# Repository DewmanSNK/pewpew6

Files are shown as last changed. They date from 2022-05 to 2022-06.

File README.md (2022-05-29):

# pewpew6
## Re-map and Rapid Fire
### Introduction

Based on buffi's original openpewpew, pewpew6 is an Arduino Nano based device for rapid fire and button remap in a JAMMA arcade cabinet. Pewpew6 supports up to 6 input buttons and can map those to any of 6 outputs. It simply connects in-line between the control panel buttons and the existing wiring harness. In an unconfigured state pewpew6 will provide simple passthrough, making it as though pewpew6 was not even installed. To load custom rapid fire and button remapping, pewpew6 leverages NFC cards. An NFC card card be configured with a desired auto fire and button remapping configuration. When the card is in proximity of the NFC reader, PewPew6 will change configuration on the fly and apply the rapid fire and remap settings stored on the card. This allows you to preconfigure you favorite buttons mappings and/or auto fire rates and store those on any number of NFC cards. 

### pewpew6 Features

- 6 button input and 6 outputs
- Button Remap
- Separate frames_on and frames_off rapid fire settings
- NFC card reader for loading settings
- 6 LED indicators show per button configuration

### NFC Card Format

Settings are stored in a 'Text Record' on the NFC card. 

Each line consists of the following comma separated values:  
(Button)(rapid enable)(frames_on)(frames_off)(Output)  

-Only one button definition per line  
-Last button definition ends with ';'  

Line Example
-------
A,0,1,1,1 = Button A, No auto fire enabled, 1 frame_on, 1 frame_off, Output 1  
**Note - When auto fire is disabled, the frame_on/frame_off vales are meaningless**  

Example Text Record 1:
--------------------
A,0,1,1,1  
B,0,1,1,2  
C,0,1,1,3  
D,0,1,1,4  
E,0,1,1,5  
F,0,1,1,6;  

The example text record 1 shown above displays the correct format. The settings in this example are the default settings stored in the Arduino.   
No rapid fire, no remapping - passthrough only.  

Example Text Record 2:
--------------------
A,0,1,1,1  
B,1,2,2,1  
C,1,1,4,1  
D,1,4,4,1  
E,1,10,1,1  
F,1,5,5,1;  

The example text record 2 shown above maps all 6 buttons to JAMMA-1  
Button A has no rapid fire, 1 frame_on, 1 frame_off, JAMMA-1  
Button B has rapid fire enabled, 1 frame_on, 1 frame_off, JAMMA-1  
Button C has rapid fire enabled, 1 frame_on, 4 frame_off, JAMMA-1  
Button D has rapid fire enabled, 4 frame_on, 4 frame_off, JAMMA-1  
Button E has rapid fire enabled, 10 frame_on, 1 frame_off, JAMMA-1  
Button F has rapid fire enabled, 5 frame_on, 5 frame_off, JAMMA-1  

Example Text Record 3:
--------------------
A,0,1,1,1  
B,0,2,2,2  
D,0,4,4,3  
E,0,10,10,4;  

The example text record 3 shown above is a fighting game example.  
Only 4 buttons are mapped, all buttons have rapid fire disabled - this is used only for button remapping and no rapid fire.

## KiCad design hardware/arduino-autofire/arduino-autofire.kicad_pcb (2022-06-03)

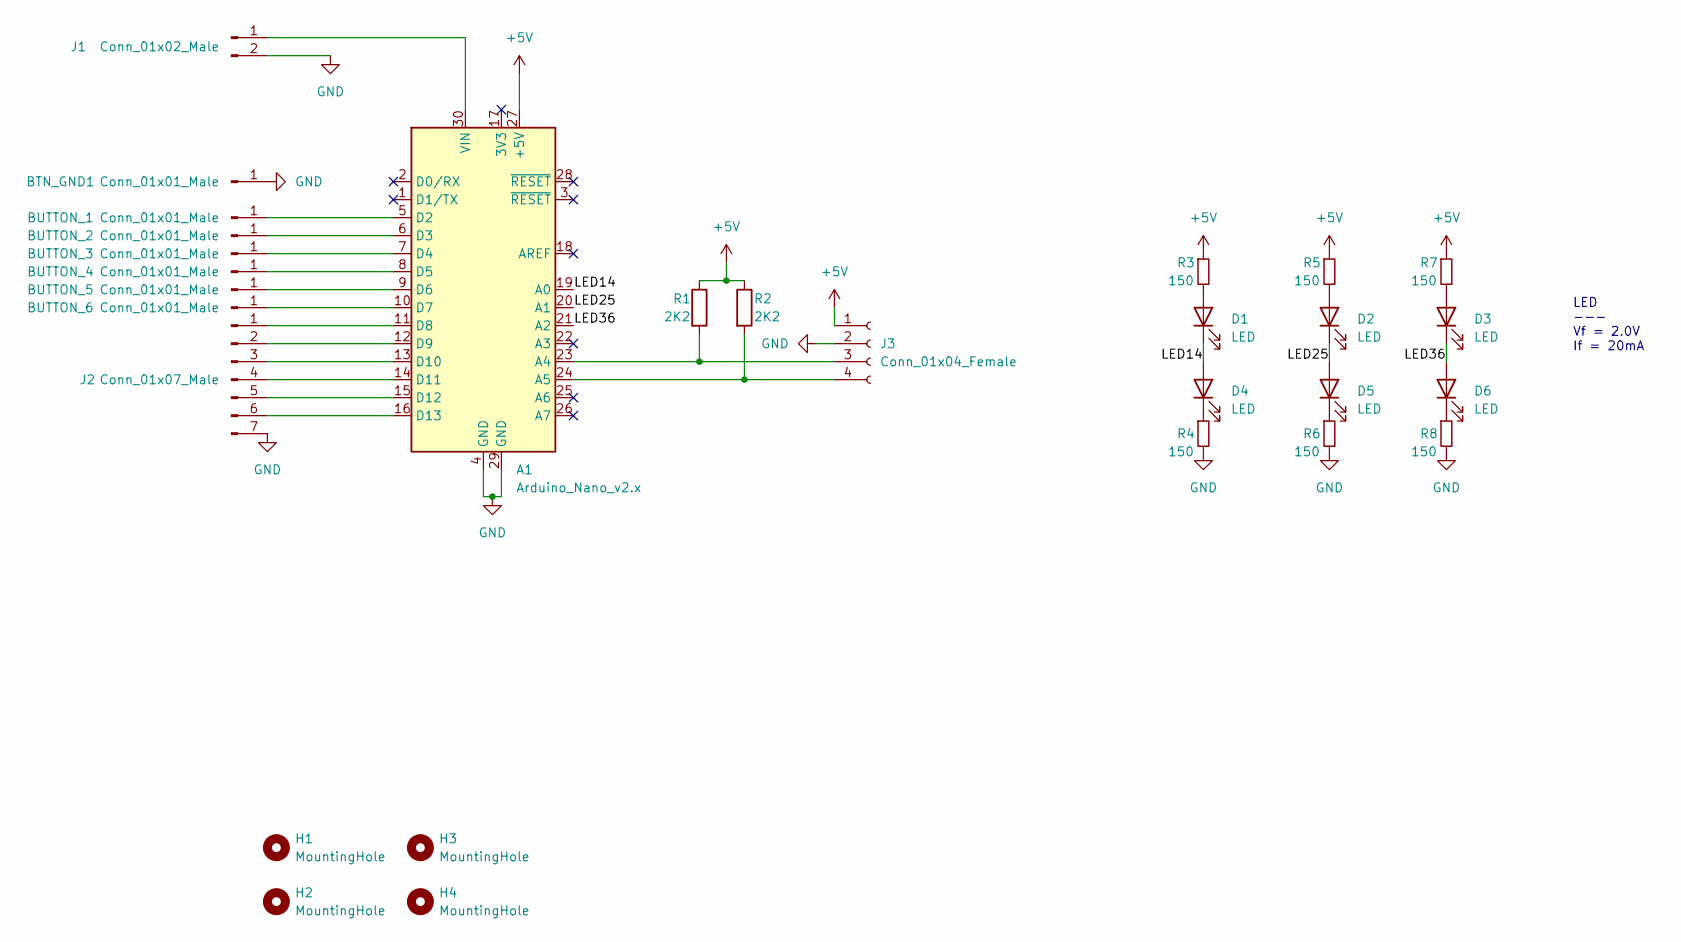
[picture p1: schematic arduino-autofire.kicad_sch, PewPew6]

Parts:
A1: Arduino_Nano_v2.x; Arduino_Nano_3D
BTN_GND1: Conn_01x01_Male; RA_Pin_D1.3mm_5.0mm
BUTTON_1, BUTTON_2, BUTTON_3, BUTTON_4, BUTTON_5, BUTTON_6: Conn_01x01_Male; RA_Pin_D1.3mm_5.0mm
D1, D2, D3, D4, D5, D6: LED; LED_0805_2012Metric_Pad1.15x1.40mm_HandSolder
H1, H2, H3, H4: MountingHole; MountingHole_3.2mm_M3
J1: Conn_01x02_Male; JST_EH_S2B-EH_1x02_P2.50mm_Horizontal
J2: Conn_01x07_Male; JST_EH_S7B-EH_1x07_P2.50mm_Horizontal
J3: Conn_01x04_Female; JST_EH_S4B-EH_1x04_P2.50mm_Horizontal
R1, R2: 2K2; R_0805_2012Metric_Pad1.20x1.40mm_HandSolder
R3, R4, R5, R6, R7, R8: 150; R_0805_2012Metric_Pad1.20x1.40mm_HandSolder

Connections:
+5V: A1.27 (+5V), J3.1, R1.1, R2.1, R3.1, R5.1, R7.1
/LED14: A1.19 (A0), D1.1 (K), D4.2 (A)
/LED25: A1.20 (A1), D2.1 (K), D5.2 (A)
/LED36: A1.21 (A2), D3.1 (K), D6.2 (A)
GND: A1.4 (GND), A1.29 (GND), BTN_GND1.1, J1.2, J2.7, J3.2, R4.2, R6.2, R8.2
unnamed: A1.5 (D2), BUTTON_1.1
unnamed: A1.6 (D3), BUTTON_2.1
unnamed: A1.7 (D4), BUTTON_3.1
unnamed: A1.8 (D5), BUTTON_4.1
unnamed: A1.9 (D6), BUTTON_5.1
unnamed: A1.10 (D7), BUTTON_6.1
unnamed: A1.11 (D8), J2.1
unnamed: A1.12 (D9), J2.2
unnamed: A1.13 (D10), J2.3
unnamed: A1.14 (D11), J2.4
unnamed: A1.15 (D12), J2.5
unnamed: A1.16 (D13), J2.6
unnamed: A1.23 (A4), J3.3, R1.2
unnamed: A1.24 (A5), J3.4, R2.2
unnamed: A1.30 (VIN), J1.1
unnamed: D1.2 (A), R3.2
unnamed: D2.2 (A), R5.2
unnamed: D3.2 (A), R7.2
unnamed: D4.1 (K), R4.1
unnamed: D5.1 (K), R6.1
unnamed: D6.1 (K), R8.1

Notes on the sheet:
LED --- Vf = 2.0V If = 20mA

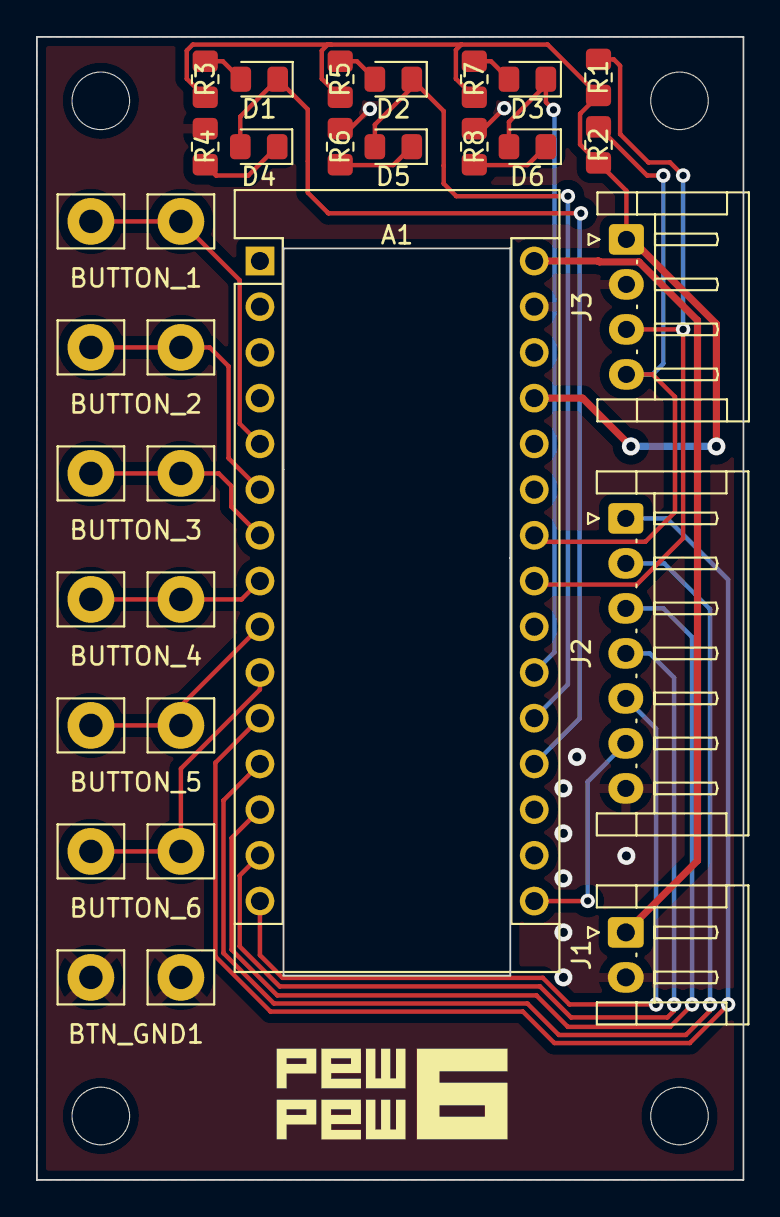
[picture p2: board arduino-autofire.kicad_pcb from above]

Board: 2 copper layers, 39.2 x 63.5 mm, 29 parts (0 on the bottom side), 26 nets.

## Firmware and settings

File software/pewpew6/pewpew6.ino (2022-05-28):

// PewPew6 - ReMap and Rapid Fire
// buffi - 2019
// dewmanSNK - 2022

// Button configs below.
// Six autofire buttons with different frequencies are allowed.
// When "input_pin" of a button is connected to GND, "output_pin" will start auto-firing.
// Each pulse is "frames_active" frames long, with "frames_inactive" frames between each pulse.

#include <Wire.h>
#include <PN532_I2C.h>
#include <PN532.h>
#include <NfcAdapter.h>


const int NUM_BUTT = 6;

const int JAMMA6 = 7;  //D7 PD7
const int JAMMA5 = 6;  //D6 PD6
const int JAMMA4 = 5;  //D5 PD5
const int JAMMA3 = 4;  //D4 PD4
const int JAMMA2 = 3;  //D3 PD3 
const int JAMMA1 = 2;  //D2 PD2

const int CONTROL6 = 5; //D13 PB5
const int CONTROL5 = 4; //D12 PB4
const int CONTROL4 = 3; //D11 PB3
const int CONTROL3 = 2; //D10 PB2
const int CONTROL2 = 1;  //D9  PB1
const int CONTROL1 = 0;  //D8  PB0


PN532_I2C pn532_i2c(Wire);
NfcAdapter nfc = NfcAdapter(pn532_i2c);
String tagId = "None";
byte nuidPICC[4];


struct AutofireConfig {
  int frames_active, frames_inactive, input_pin, output_pin, autofire_state, autofire_active;
};

AutofireConfig BUTTON_1 = {
  /*frames_active=*/1,
  /*frames_inactive=*/1,
  /*input_pin=*/CONTROL1,
  /*output_pin=*/JAMMA1,
  /*autofire_state=*/0,
  /*autofire_active=*/0  
};

AutofireConfig BUTTON_2 = {
  /*frames_active=*/1,
  /*frames_inactive=*/1,
  /*input_pin=*/CONTROL2,
  /*output_pin=*/JAMMA2,
  /*autofire_state=*/0,
  /*autofire_active=*/0   
};

AutofireConfig BUTTON_3 = {
  /*frames_active=*/1,
  /*frames_inactive=*/1,
  /*input_pin=*/CONTROL3,
  /*output_pin=*/JAMMA3,
  /*autofire_state=*/0,
  /*autofire_active=*/0   
};

AutofireConfig BUTTON_4 = {
  /*frames_active=*/1,
  /*frames_inactive=*/1,
  /*input_pin=*/CONTROL4,
  /*output_pin=*/JAMMA4,
  /*autofire_state=*/0,
  /*autofire_active=*/0   
};

AutofireConfig BUTTON_5 = {
  /*frames_active=*/1,
  /*frames_inactive=*/1,
  /*input_pin=*/CONTROL5,
  /*output_pin=*/JAMMA5,
  /*autofire_state=*/0,
  /*autofire_active=*/0   
};

AutofireConfig BUTTON_6 = {
  /*frames_active=*/1,
  /*frames_inactive=*/1,
  /*input_pin=*/CONTROL6,
  /*output_pin=*/JAMMA3,
  /*autofire_state=*/0,
  /*autofire_active=*/1   
};

AutofireConfig *BUTTONS[] = { &BUTTON_1, &BUTTON_2, &BUTTON_3, &BUTTON_4, &BUTTON_5, &BUTTON_6 };


ISR(TIMER1_COMPA_vect) {

  //Pin data read in
  int pinb_r = PINB;

  //Port data to be set
  int portd_w = 0;
  int ddrd_w = 0;
  boolean firing = false;

  for (int i=0; i<NUM_BUTT; i++){

    if (pinb_r & ( 1 << BUTTONS[i]->input_pin)){ //Button NOT PRESSED
    
      BUTTONS[i]->autofire_state = 0;
      portd_w |= ~( 1 << BUTTONS[i]->output_pin); //- Set Pin LOW
      //ddrd_w  |= ~( 1 << BUTTONS[i]->output_pin); //- Sets Pin as INPUT // Take no action when button no pressed
    
    } else {
      if (BUTTONS[i]->autofire_active){
        if (BUTTONS[i]->autofire_state++ < BUTTONS[i]->frames_active){
      
          portd_w |= ~( 1 << BUTTONS[i]->output_pin); //- Set Pin LOW
          ddrd_w  |=  ( 1 << BUTTONS[i]->output_pin); //- Sets Pin as OUTPUT
          firing = true;
      
        } else {
      
			portd_w &= ~( 1 << BUTTONS[i]->output_pin); //- Set Pin LOW
			ddrd_w  &= ~( 1 << BUTTONS[i]->output_pin); //- Sets Pin as INPUT
      
		  }
          if (BUTTONS[i]->autofire_state > (BUTTONS[i]->frames_active + BUTTONS[i]->frames_inactive) ){
			  BUTTONS[i]->autofire_state = 0;
          }
      } else {
        
        portd_w |= ~( 1 << BUTTONS[i]->output_pin); //- Set Pin LOW
        ddrd_w  |=  ( 1 << BUTTONS[i]->output_pin); //- Sets Pin as OUTPUT

        }
    
      }
      
  //Aggrigate pin states through the loop
  portd_w |= portd_w;
  ddrd_w  |= ddrd_w;
  }
  
  //Assign pin states to pins (Single write to port registers per ISR)
  //PORTD = portd_w;
  DDRD  = ddrd_w;
}

void setup() {
  //Serial.begin(9600);
  nfc.begin();	
  
  DDRB  = B00000000; // set PORTB (digital 13~8) to INPUT
  PORTB = B11111111; // set PORTB to HIGH. INPUT_PULLUP
  
  DDRD  = B11111111; // set PORTD (digital 7~0) to OUTPUT

  // Setup timer.
  cli();
  TCCR1A = 0x00; // Timer 1 in normal mode
  TCCR1B = 0x02; // 16MHz clock with prescaler, TCNT1 increments every .5 uS
  TCNT1  = 0;    // Initialize counter to 0
  OCR1A = 33333; // = 16666 microseconds (each count is .5 us)
  TIMSK1 |= (1 << OCIE1A); // Enable compare interrupt
  sei();
  
}

void loop(){ 

  delay(5000);
  if (nfc.tagPresent())
  {
    NfcTag tag = nfc.read();
    Serial.println(tag.getTagType());
    Serial.print("UID: ");Serial.println(tag.getUidString()); // Retrieves the Unique Identification from your tag

    if (tag.hasNdefMessage()) // If your tag has a message
    {

      NdefMessage message = tag.getNdefMessage();
      Serial.print("\nThis Message in this Tag is ");
      Serial.print(message.getRecordCount());
      Serial.print(" NFC Tag Record");
      if (message.getRecordCount() != 1) { 
        Serial.print("s");
      }
      Serial.println(".");

			// If you have more than 1 Message then it wil cycle through them
			int recordCount = message.getRecordCount();
			for (int i = 0; i < recordCount; i++)
			{
				Serial.print("\nNDEF Record ");Serial.println(i+1);
				NdefRecord record = message.getRecord(i);
			
				int payloadLength = record.getPayloadLength();
				byte payload[payloadLength];
				record.getPayload(payload);
				Serial.println(payloadLength);
			
				char *token = 0;
				//Sneaky skip first 3 garbage characters in NFC card read 
				token = strtok((payload+3), ",");
				int tk = 0;
				while (token != NULL){
					//Buttons A-F (ASCII A=65, F=70)
					tk = token[0];
					if (tk >= 65 & tk <= 70 ){
					Serial.println(token);
					token = strtok(NULL, ",");
					Serial.println(token);
					BUTTONS[(tk-65)]->autofire_active = atoi(token);
					token = strtok(NULL, ",");
					Serial.println(token);
					BUTTONS[(tk-65)]->frames_active = atoi(token);
					token = strtok(NULL, ",");
					Serial.println(token);
					BUTTONS[(tk-65)]->frames_inactive = atoi(token);
					token = strtok(NULL, ",\n");
					Serial.println(token);
					BUTTONS[(tk-65)]->output_pin = (atoi(token) + 1);
					}
					
					token = strtok(NULL, ",");
			
				}

			}
    }
	
  }

}
